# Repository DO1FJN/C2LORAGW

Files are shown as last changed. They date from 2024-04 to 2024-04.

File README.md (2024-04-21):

# Codec2 Lora Gateway

**Attention:** This project is in a very early alpha state. It lacks in some basic features and in documatation.

## Overview

This opensource project 'C2LoRaGW' connects LoRa (SemTech SX126x) based radios with internet / ham-net based repeater software.
To transport speech data using low bandwidth / bitrates C2LoRaGW uses only Codec2 within the UDP-RTP datastream.

The datastream used in the internet / ham-net derives from a 2012 project 'HAMdLNK' and uses the same format like my D-Star
proof-of-concept software from this time. A demo software 'DV-RPTR-App' was already developed and is still in use (now with
localaudio using pipewire) to test the UDP link.

On UHF side I defined 10 modes using the lower bandwidth modulations of the LoRa IC: 10,15,20 and 31kHz to transmit with 100%
duty on a frequency within 70cm ham-radio band (430-440MHz in Germany). C2LoRaGW acts as a hotspot transmitting and receiving on
the same frequency half-duplex. There is an option to add a 2nd transceiver to it and build a full duplex relay base station.

Because the fact that not ready-to-use LoRa based radios exist, this project contains also audio in- and output using cheap I2S
modules plus display an simple UI on a TFT or OLED display.

More information is in the [wiki](https://github.com/DO1FJN/C2LORAGW/wiki)

### Hardware

The project is preconfigured to run on a Heltec WiFi LoRa V3 board (433-510MHz).

A ready to use 80x50mm PCB *"C2LORAGW"* containing an E22-400M30S (or M33S) and a ESP32-S3 module is available as a KiCad
project: All spare IO's are routed to a 2.54mm pin header for adding extensions. This board can be powered by an USB 2A charger
or an LiPo / LiIon 1S battery. To simplify the design this board doesn't contain a charger or power switch jet (can be added on
a separate board). This PCB is sized to fit into an Hammond or Fisher aluminum case, but also have 4 mounting holes (M3).

More information is in the [wiki](https://github.com/DO1FJN/C2LORAGW/wiki)

### Firmware

Because the project is based around the ESP32-S3 (only this µC) the firmware needs only the EspressIf IDF developing environment.
As IDE there are some options, I used Microsoft VS Code. Setup like on EspressIf documentation described. This project uses
other opensource: Codec2 for example and the SemTech sx126x driver.

## Getting Started

First: READ all available documentation (it is not much). See "documentation" folder and use the
[wiki](https://github.com/DO1FJN/C2LORAGW/wiki).

Get some compatible hardware or build some:

Get an ESP32-S3 wroom based dev-kit or similar. Connect a SX1262 or SX1268 based Lora module (equipped for UHF!) to it. There is
almost no constrains in pinning the SPI or the additional GPIO pins needed.

### Flash Precompiled Firmware

1. Download the [ESP32 flashing utility](https://github.com/cpq/esputil).
2. Download the precompiled firmware image (ZIP file with a few binary images)
3. Flash the stuff

### Get Repository

* Install VisualStudio Code, add the EspressIf toolchain + esp-idf (or just the bare EspressIf stuff)
* Clone the repository from here (code button)
* copy one of the provided sdkconfig to "sdkconfig"
* Modify the GPIO and other settings in ./components/boards/breadboard.h or create a new board definition file for your target
* Config the project...  `idf.py menuconfig` (select the proper console for your target)
* Build + flash it... `idf.py flash`

tbd

### First Connection

Run the EspressIf monitor or something similar (Putty) to see C2LORA boot. After this, it shows a command prompt. Using typed
commands to establish a wifi connection (station mode) or change C2LORA settings, hostname, callsign and so on.

### Calibration

Because of the narrow bandwidth used a frequency calibration of crystal based LoRa modules is mandatory. The frequency needs to
be within a range of +/- 2.6kHz of the target value. TCXO radio modules are much better and a calibration is not required.

Calibration requires a frequency counter or an similar device to view a carrier in the 70cm band. Start calibration using the
command line:

`c2lora cali 1`

After this command the device transmits a continuous wave (unmodulated carrier). On the terminal the actual used offset value is
shown. Measure the difference between the carrier and the target frequency and add or subtract it from the shown offset. Type
in the new calculated offset:

`c2lora offset <new value>`

After this, the carrier moves to a new position.

**Warning:** Use an antenna or an dummy load while doing this!

A rule of thumb: Cheap crystal based modules have shown an initial offset of +17kHz below the target.

If done, turn of the transmitter with:

`c2lora cali 0`

### Save C2LORA Settings

All settings (frequency, mode, txpower and offset) are saved with the command

`c2lora save`

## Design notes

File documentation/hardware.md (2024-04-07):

# C2LoRaGW Hardware

## Prototyp 1 Board (PT01)

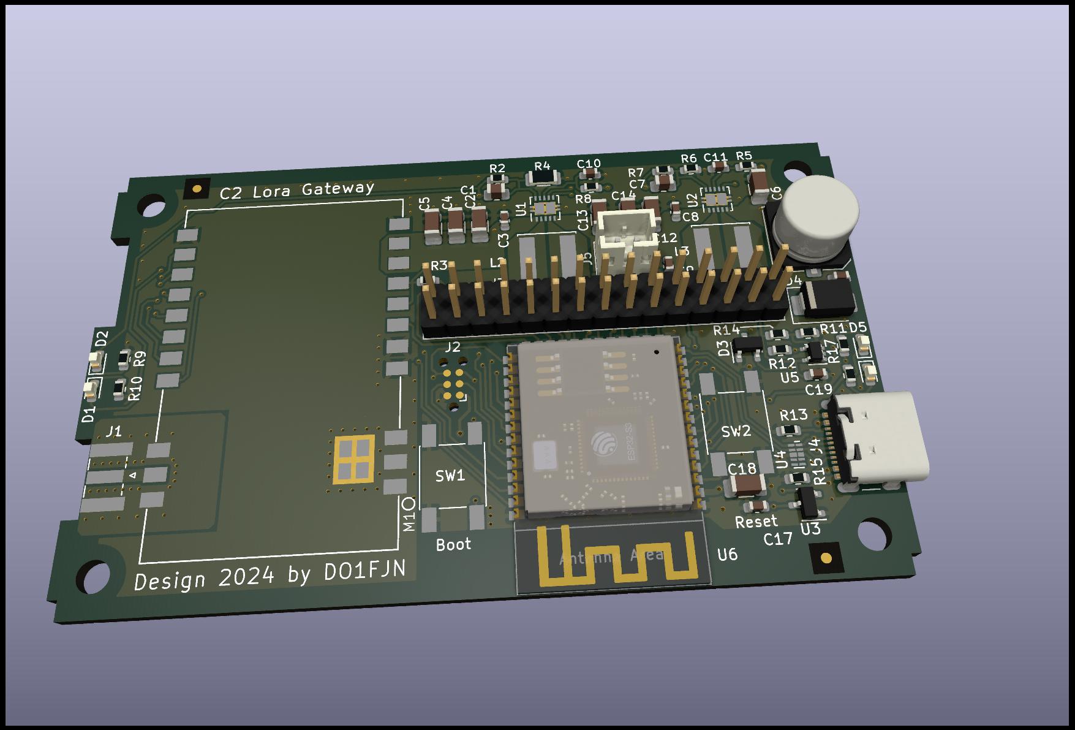
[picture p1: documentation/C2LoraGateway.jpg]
Rendering C2LORAGA Prototype 1


### Issues

ZRXE125 polarity wrong. Part needs to be "upside down" or 180° rotated. An additional capacitor is placed on R11 to
prevent fast switch on/off at the exact trigger voltage.

The 3.3VCC supply drops below APX809S31SA trigger level, if a sudden load happen on 5V rail (turning it on or transmit)
only if the input voltage is in the range between 3.8V - 3.3V (some mV above 3.3V output).

Main TPS63000 is fixed to "power save mode" - not the best decision.

### Sheet and Layout

[Sheet PDF](C2LoRaGW_sheet_PT01.pdf)

[Board Layout](C2LoRaGW_pcbtop_PT01.pdf)

## Full-Duplex Relay-Addon (FDR01)

This addon is in planning stage.

tbd

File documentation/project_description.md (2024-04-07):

# C2LoRa

## What Is C2LoRa?

C2LoRa stands for "Codec2 over LoRa". It utilizes a SemTech SX126x IC (SX1261, SX1262 or SX1268) as a transceiver for
digital speech data. This digital speech data is heavily compressed by an opensource vocoder "Codec2".

## What Is Codec2

Codec2 is a vocoder. Developed by David Rowe, Codec2 is a open source encoder and decoder specialized for human speech.
This algorithm is used to get speech data with only 3.2 down to 0.7 kbit/s (normal phone quality PCM audio: 64kbit/s).

## What Is HAMdLNK

HAMdLNK (ham radio digital voice link) is a protocol definition that adds a subframe definition to a UDP-RTP packet. It's a way
to uses UDP-RTP and pack some more information into it beside the speech data like sender, recipient and much more.

## What Is The 'Gateway'

C2 LoRa Gateway - the name of this project - describes the main function: A C2LoRa reception is forwarded to an IP address and
incoming HAMdLNK packets will be assembled and transmitted. The forwarded IP address can configured as an IPv4 broadcast or IPv6
multicast or as a URL (DNS resolvable name). IP base communication is done using the integrated

In the simplest scenario 2 devices are within the same local LAN. One uses a Gateway configuration, the other is in a 'dongle'
mode. With the 'dongle' device an operator can remotely receive and transmit away from the main station (roof antenna).

## How It Works

C2LoRa defines 10 slightly different modes. All modes in common are the use of a narrowish bandwidth (10-31kHz) and a very low
spreading factor (SF5 o SF6). For this reason the modulation isn't compatible with older SX127x IC's. In all modes speech will
be framed into 480ms long packets (6 or 12 Codec2 frames). These packets are transmitted using the mode-depended parameters. On
air such a packet is roughly as long as the voice (480ms) so that only minimal gaps exists and a transmission is near 100% duty.

The first packet of every transmission contains a tiny header so that the first transmission is between 520-580ms long.

Here is the mode overview: [C2LORA modes](C2LORA modes.md)

## Hardware Setup

This project utilizes EspressIF IDF toolchain and will compile only on a ESP32-S3 (wroom module) in the moment. This SOC is
fast enough to handle the Codec2 en- and decoding. Besides the SOC there is an module with an SX126x IC needed. In my design
it's a EByte E22-400M30S. This model is equipped with a TCXO so that the frequency is stable and even w/o calibration usable.
Module w/o a TCXO need a calibration because the frequency is very off (I measured 17kHz for my testing modules). Because of
the narrow bandwidth the modules need to be calibrated (max 2.6kHz off). Beside the power regulator(s) and a USB-C plug plus 2
buttons: That's really is it.

### Optional Hardware

There is "no limit". In the moment I added support for the common MAX98357A I2S audio amplifier and an INMP441 microphone. The
BOOT key acts as a PTT. A ST7789 TFT display can be also used. I plan to put more stuff (touchscreen support) into in so that
for example a LilyGo T-Deck can be used as a handheld radio.

### Developed Hardware

"C2LORAGW" description [here](hardware.md)

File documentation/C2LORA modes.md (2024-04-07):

# C2LORA Transmission Modes

The proper transmission mode must be known in advance. Like the frequency it is set once. There are 10 modes defined.

## Change Mode

Open a terminal / monitor to the board. Type

`c2lora mode x`

and hit enter.

(replace the 'x' with the mode number 0 to 9 or with the exact mode name (like "15kHz_1600").

## Mode Details

All modes have in common a 480ms long packet that have the same amount of Codec2 digital speech in it. There are almost no gaps
between packets. The transmitter sends out a stream of packet continuously (100% duty).

The first packet starts with a header containing some information:
* callsign (max 7 characters)
* recipient (max 7 characters, specials like "CQCQCQ" possible)
* kind of station (kos) and "was repeated" bit
* a 16bit crc for the values above
* (not in all modes) area code
* (not in all modes) locator

If configured with a frequency shift, the downstream (higher frequency, usually transmitted by a relay station / repeater) uses
inverted IQ for better separation. The upstream still uses normal IQ, same like in single frequency mode.

For all modes the SYNC WORD 1464h is used.

## Overview

| mode | name | bandwidth | SF | CR  | Codec2 | RX sensitivity | eff. bitrate |
| --- | ---- | :---: | -- | --  | -----: | ---: | ---: |
|C2M0_10LR  | 10kHz_700C | 10kHz | SF5 | 4/7 | 700C | -129.8dBm |  930bps |
|C2M1_15LR  | 15kHz_700C | 15kHz | SF6 | 4/6 | 700C | -130.6dBm |  977bps |
|C2M2_15STD | 15kHz_1300 | 15kHz | SF5 | 4/6 | 1300 | -128.1dBm | 1628bps |
|C2M3_15MQ  | 15kHz_1400 | 15kHz | SF5 | 4/6 | 1400 | -128.1dBm | 1628bps |
|C2M4_15HQ  | 15kHz_1600 | 15kHz | SF5 | 4/5 | 1600 | -128.1dBm | 1953bps |
|C2M5_20LR  | 20kHz_1300 | 20kHz | SF6 | 4/5 | 1300 | -129.3dBm | 1524bps |
|C2M6_20 | 20kHz_2400 | 20kHz | SF5 | 4/5 | 2400 | -126.8dBm | 2604bps |
|C2M7_31STD | 31kHz_1600 | 31kHz | SF6 | 4/6 | 1600 | -127.6dBm | 1953bps |
|C2M8_31LL  | 31kHz_2400 | 31kHz | SF5 | 4/7 | 2400 | -125.1dBm | 3255bps |
|C2M9_31HQ  | 31kHz_3200 | 31kHz | SF5 | 4/5 | 3200 | -125.1dBm | 3906bps |

* bandwidth (BW) refers to the double sideband (DSB)
* spreading factor (SF): only the lowest two SF are used, not compatible with SX127X devices
* FEC coding rate (CR): forward error detection + correction overhead (4/5 means 4 data bits encoded with 5 bits on air)
* effective bitrate: calculated raw bitrate over the air

## Details

### C2M0_10LR "long range"

Having only a 12.5kHz wide channel to operate, this is the only mode left. A SX126x IC can transmit even with a narrower
bandwidth of 7.8kHz, but there is no benefit to use it.

With a BW of 10.4kHz and SF5 there is room to a increased CR for better single bit error resistance . The audio quality of
Codec2 in 700C mode is acceptable.

* minimum preamble length 12 = 36.86ms
* default preamble length 15 = 46.08ms, first packet (with header) 14
* payload size = 47 bytes (1 frame start byte, 42 bytes speech data, 4 bytes for cyclic data)
* header size = 13 bytes (no area code, no locator)
* first packet onair time = 580ms

### C2M1_15LR "long range"

A 15.6kHz wide signal is used to operate in a 25kHz wide channel. Using SF6 results in longer symbol times and in a more
resilient signal at the cost of bitrate. The purpose of C2M1_15LR is to get really far out.

* default preamble length 12 = 49.15ms, first packet (with header) 14
* payload size = 48 bytes (1 frame start byte, 42 bytes speech data, 5 bytes for cyclic data)
* header size = 13 bytes (no area code, no locator)
* first packet onair time = 580ms

### C2M2_15STD "universal"

With a slightly better CR and more room for extra data this mode is versatile but still lacks in additional header information.

* minimum preamble length 12 = 24.58ms
* default preamble length 15 = 30.72ms, first packet (with header) 20
* payload size = 87 bytes (1 frame start byte, 78 bytes speech data, 8 bytes for cyclic data)
* header size = 15 bytes (with area code, no locator)
* first packet onair time = 560ms

### C2M3_15MQ "better speech"

Just like *C2M2_15STD*, but with Codec2 1400 bits per second and less additional data (slower cyclic data rate).

* minimum preamble length 12 = 24.58ms
* default preamble length 15 = 30.72ms, first packet (with header) 20
* payload size = 87 bytes (1 frame start byte, 84 bytes speech data, 2 bytes for cyclic data)
* header size = 15 bytes (with area code, no locator)
* first packet onair time = 560ms

### C2M4_15HQ "even better speech quality"

Utilizing only a CR of 4/5 gives room for more speech data in exchange for robustness.

* minimum preamble length 12 = 24.58ms
* default preamble length 14 = 28.76ms, first packet (with header) 20
* payload size = 105 bytes (1 frame start byte, 96 bytes speech data, 8 bytes for cyclic data)
* header size = 15 bytes (with area code, no locator)
* first packet onair time = 550ms

### C2M5_20LR "better quality long range"

A wider bandwidth of 20.8kHz is used in combination with SF6. So a Codec2 1300 stream will fit event with a good receiver
sensitivity. Only with the base CR of 4/5 possible.

* minimum preamble length 12 = 36.86ms (recommended by SemTech)
* default preamble length 11 = 33.79ms, first packet (with header) 13
* payload size = 81 bytes (1 frame start byte, 78 bytes speech data, 2 bytes for cyclic data)
* header size = 15 bytes (with area code, no locator)
* first packet onair time = 560ms

### C2M6_20 "speech data only"

With this mode a high quality Codec2 stream (2400) is used to get a lower latency even within a 20.8kHz wide transmission. The
latency aspect can improve repeated connection (HAMdLNK) but because of the sampling + encoding time (~32ms) there is no full
effect on a local transmission.

* minimum preamble length 12 = 18.43ms
* default preamble length 12 = 18.43ms, first packet (with header) 13
* payload size = 145 bytes (1 frame start byte, 144 bytes speech data, nothing left)
* header size = 15 bytes (with area code, no locator)
* first packet onair time = 525ms

### C2M7_31STD "widband standard"

Having room for a 31.2kHz wide transmission this mode utilizes SF6 to transport Codec2 1600.

* minimum preamble length 12 = 24.58ms
* default preamble length 16 = 32.77ms, first packet (with header) 13
* payload size = 105 bytes (1 frame start byte, 96 bytes speech data, 8 byte extra)
* header size = 21 bytes (with area code and locator)
* first packet onair time = 560ms

### C2M8_31LL "low latency"

* minimum preamble length 12 = 12.29ms
* default preamble length 12 = 12.29ms, first packet (with header) 20
* payload size = 160 bytes (1 frame start byte, 144 bytes speech data, 15 byte extra)
* header size = 15 bytes (with area code, no locator)
* first packet onair time = 530ms

### C2M9_31HQ "high quality"

At the cost of bandwidth, FEC and RX sensitivity this it the mode to transport Codec2 at the highest quality possible.

* minimum preamble length 12 = 12.29ms
* default preamble length 13 = 13.31ms, first packet (with header) 14
* payload size = 222 bytes (1 frame start byte, 192 bytes speech data, 29 byte extra)
* header size = 20 bytes (with area code and locator)
* first packet onair time = 520ms

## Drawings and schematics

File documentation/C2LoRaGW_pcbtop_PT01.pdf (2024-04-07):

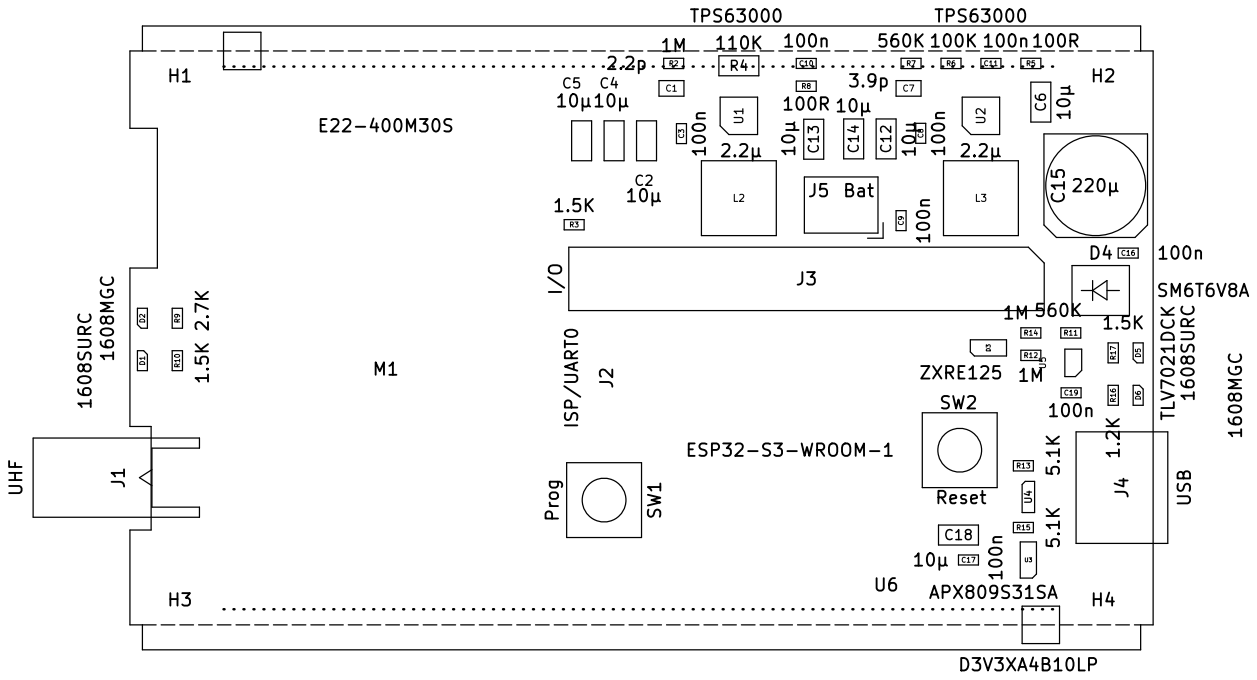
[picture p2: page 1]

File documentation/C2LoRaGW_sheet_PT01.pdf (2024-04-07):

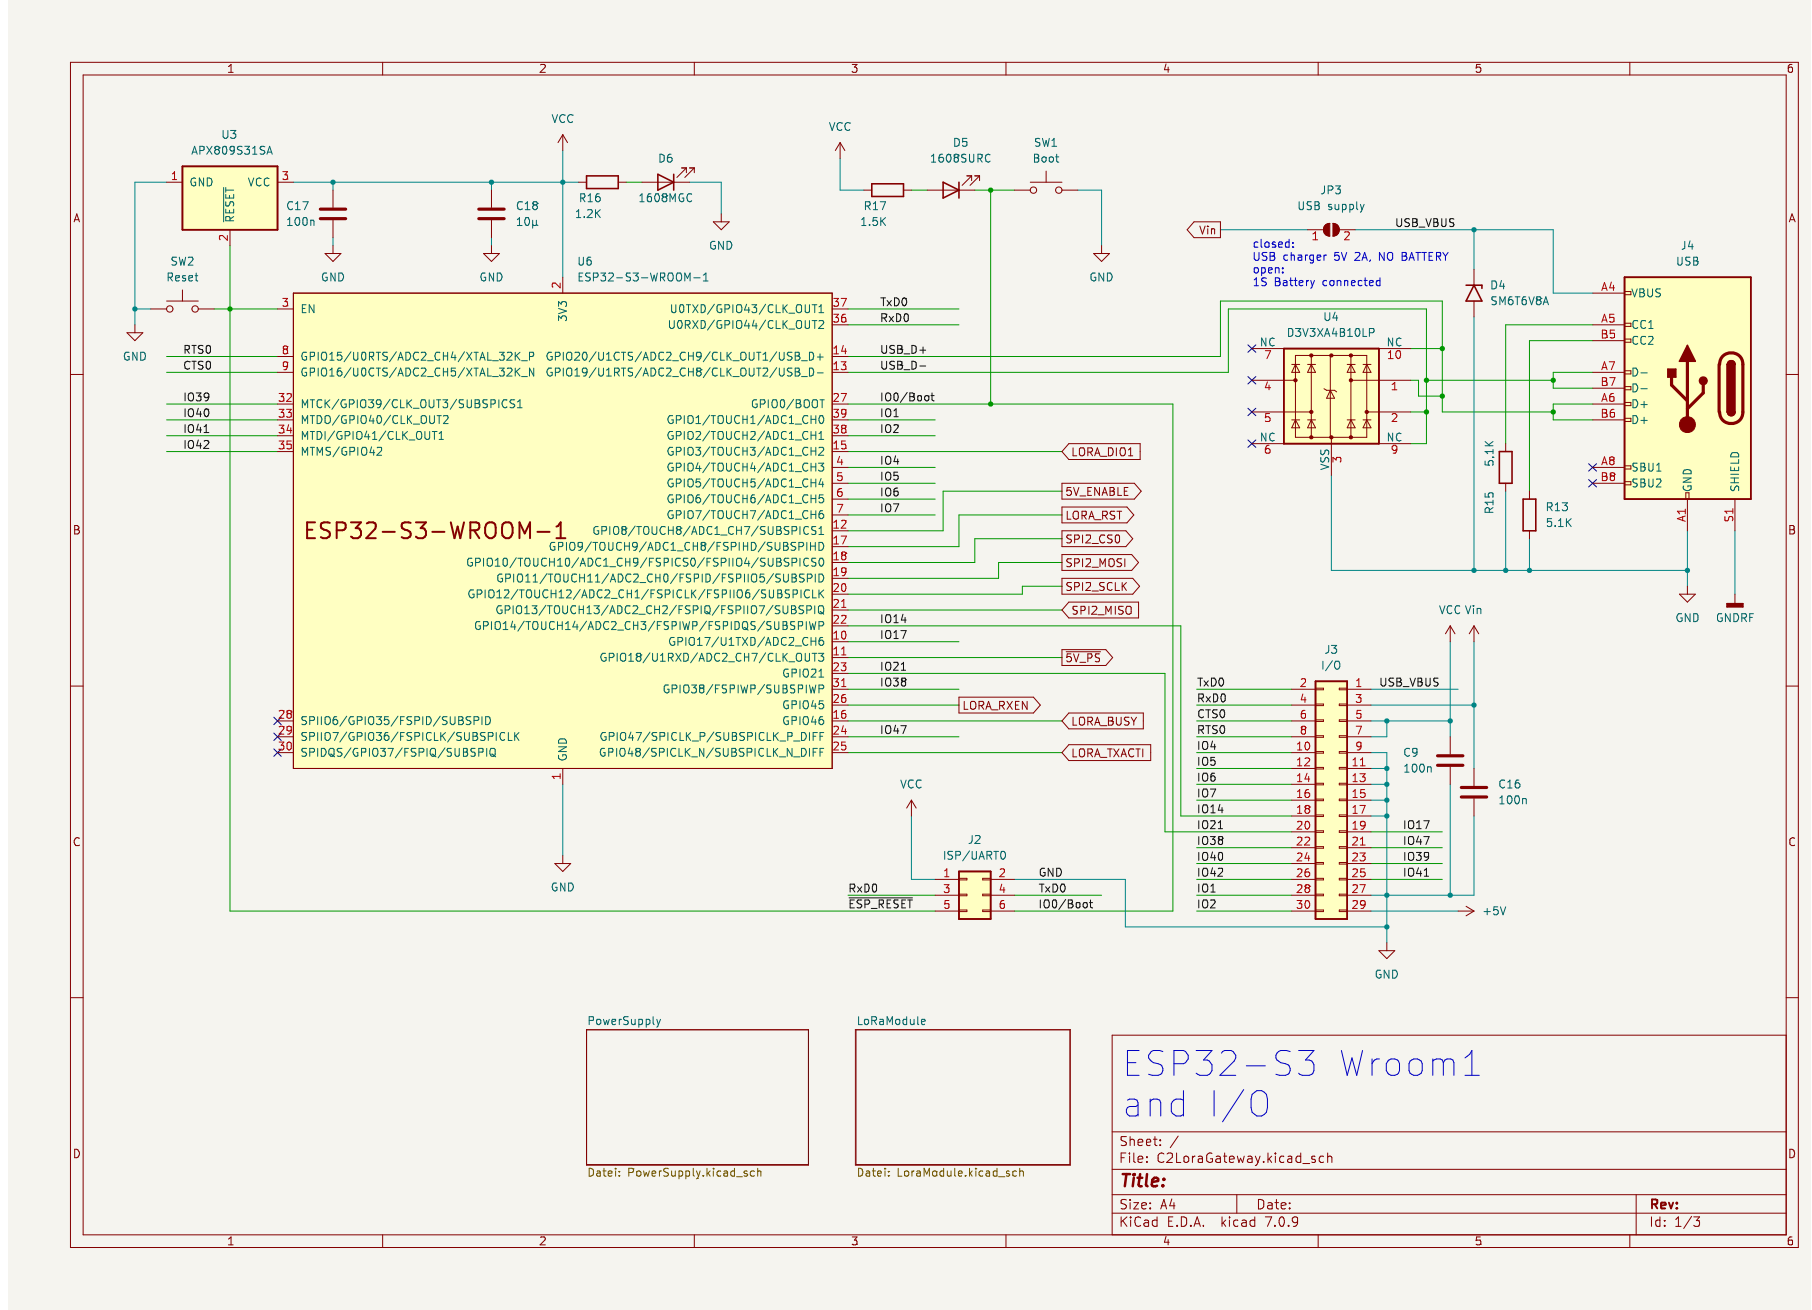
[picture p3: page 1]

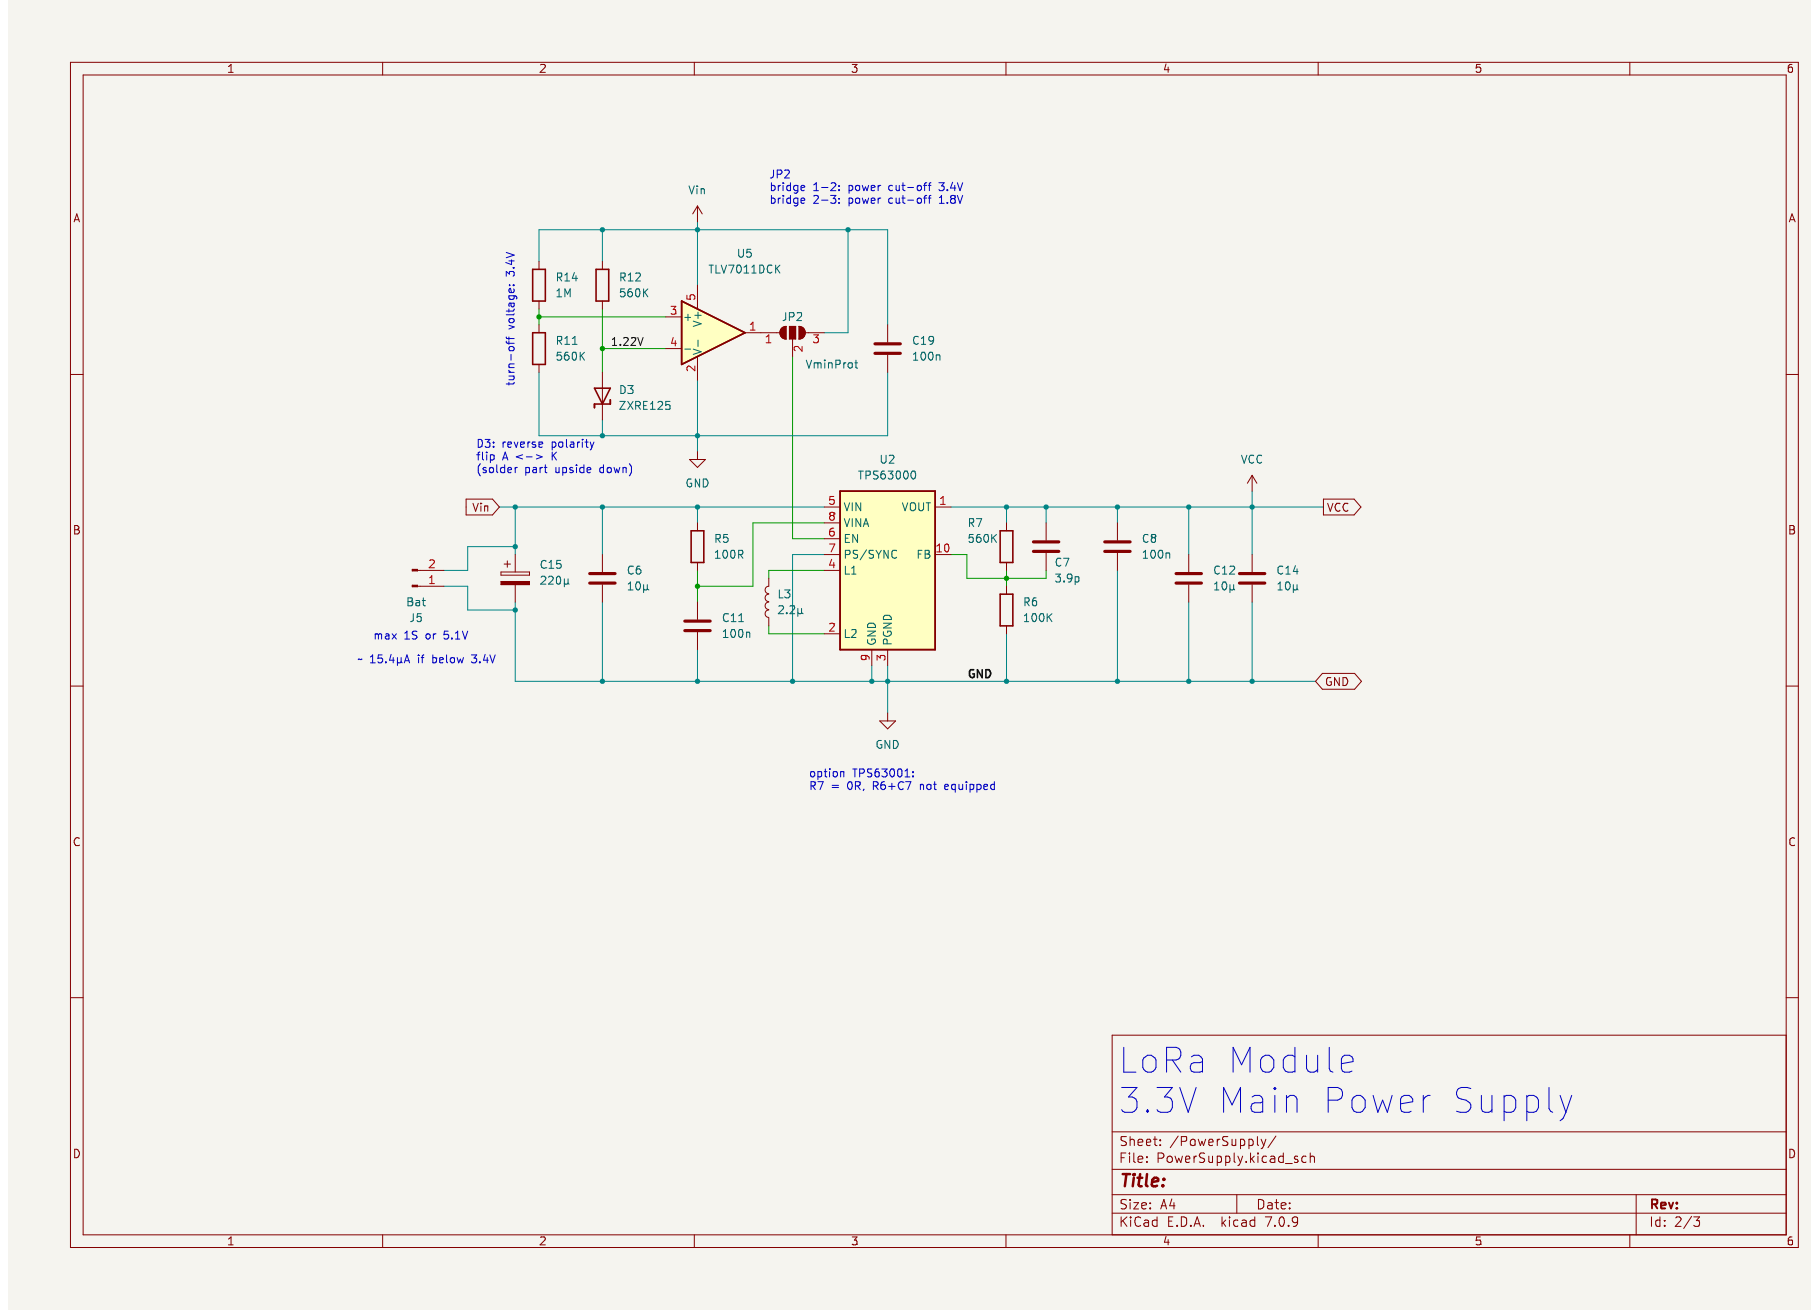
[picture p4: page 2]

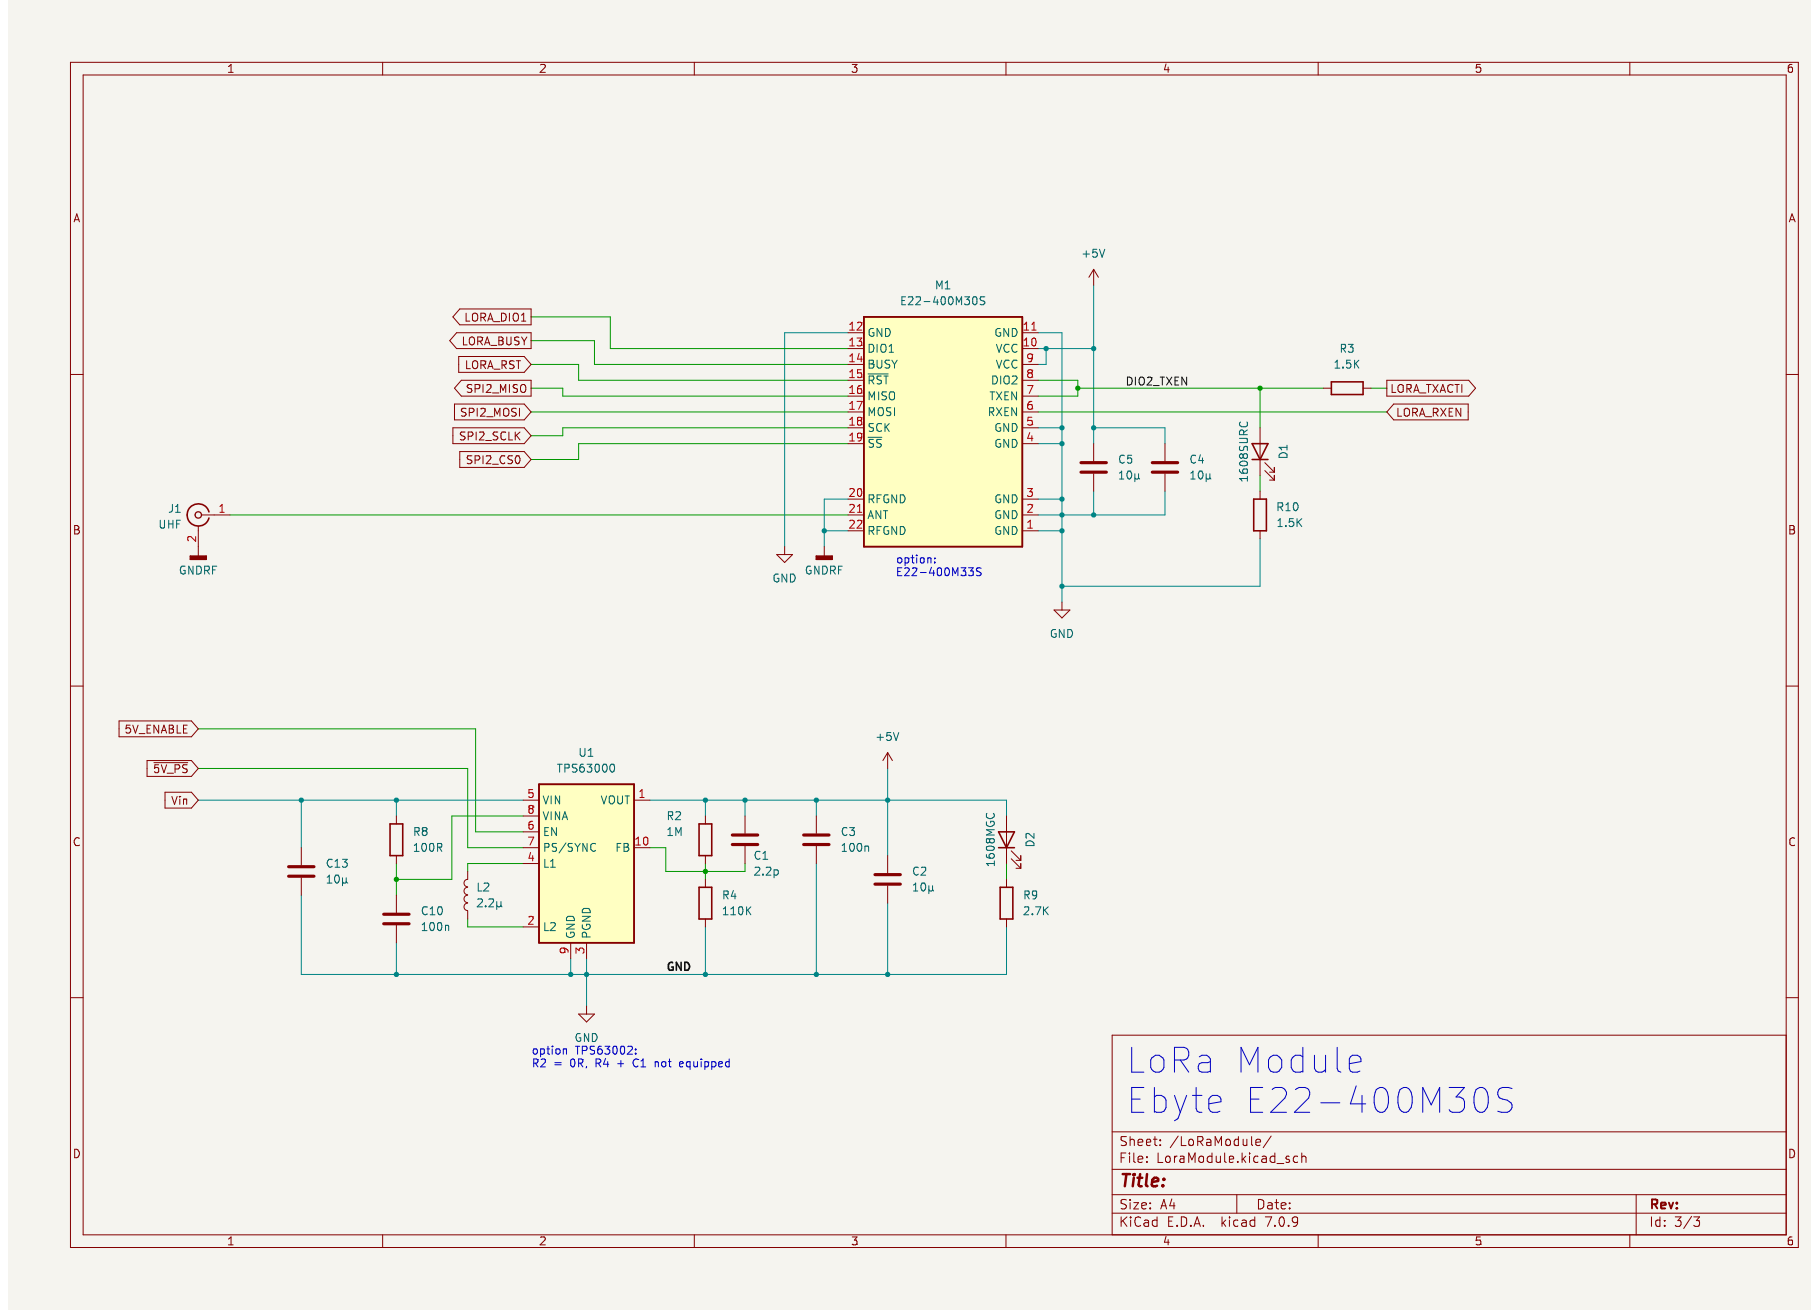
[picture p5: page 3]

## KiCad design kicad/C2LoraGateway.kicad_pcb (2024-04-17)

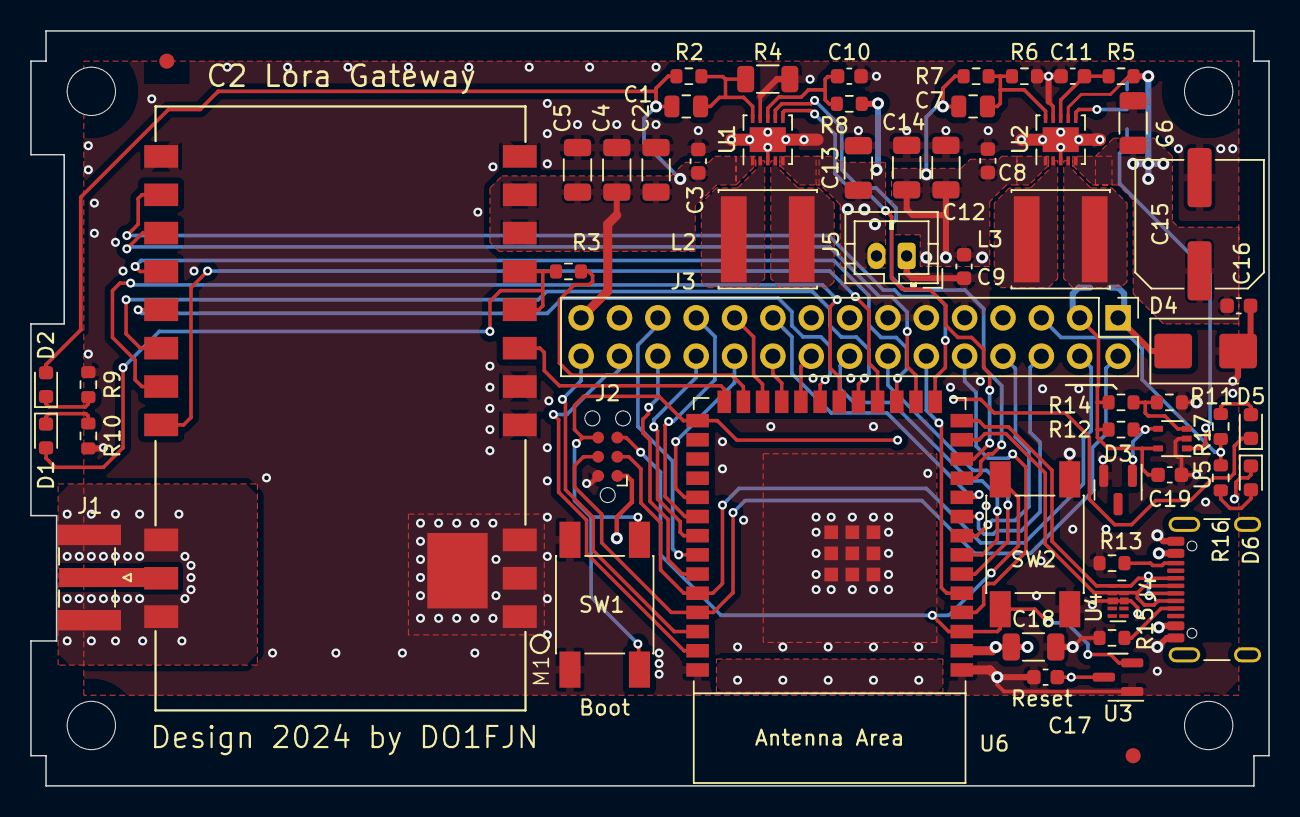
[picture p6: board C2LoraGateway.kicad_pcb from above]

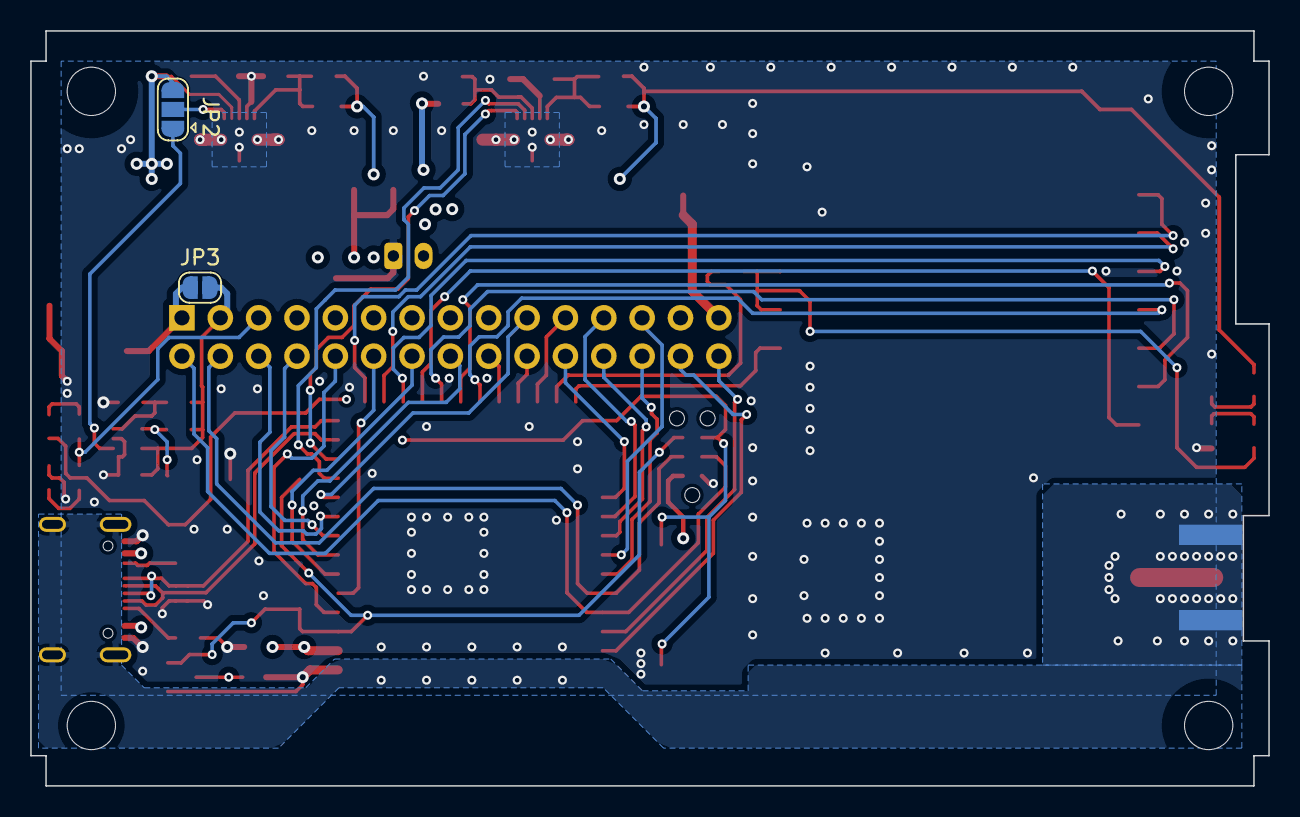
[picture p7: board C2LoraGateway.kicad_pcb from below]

Board: 4 copper layers, 82.0 x 50.0 mm, 65 parts (2 on the bottom side), 60 nets.

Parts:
C1: 2.2p; C_0805_2012Metric
C2, C4, C5, C6, C12, C13, C14, C18: 10µ; C_1206_3216Metric
C3, C8, C9, C10, C11, C16, C17, C19: 100n; C_0603_1608Metric
C7: 3.9p; C_0805_2012Metric
C15: 220µ; C_Elec_8x6.2
D1, D5: 1608SURC; LED_0603_1608Metric
D2, D6: 1608MGC; LED_0603_1608Metric
D3: ZXRE125; SOT-23
D4: SM6T6V8A; D_SMB
FID1, FID2: Fiducial_1mm_Sqare; Fiducial_1mm_Square
H1, H2, H3, H4: MountingHole_3.2mm_M3
J1: UHF; SMA_Samtec_SMA-J-P-X-ST-EM1_EdgeMount
J2: ISP/UART0; Tag-Connect_TC2030-IDC-NL_2x03_P1.27mm_Vertical
J3: I/O; PinHeader_2x15_P2.54mm_Vertical
J4: USB; USB_C_Receptacle_GCT_USB4105-xx-A_16P_TopMnt_Horizontal
J5: Bat; JST_PH_B2B-PH-K_1x02_P2.00mm_Vertical
JP2: VminProt; SolderJumper-3_P1.3mm_Open_RoundedPad1.0x1.5mm
JP3: USB supply; SolderJumper-2_P1.3mm_Open_RoundedPad1.0x1.5mm
L2, L3: 2.2µ; L_Changjiang_FNR6045S
M1: E22-400M30S
R2, R14: 1M; R_0603_1608Metric
R3, R10, R17: 1.5K; R_0603_1608Metric
R4: 110K; R_1206_3216Metric
R5, R8: 100R; R_0603_1608Metric
R6: 100K; R_0603_1608Metric
R7, R11, R12: 560K; R_0603_1608Metric
R9: 2.7K; R_0603_1608Metric
R13, R15: 5.1K; R_0603_1608Metric
R16: 1.2K; R_0603_1608Metric
SW1: Boot; SW_Push_Switronic_IT1102WB8
SW2: Reset; SW_Push_Switronic_IT1102WB8
U1, U2: TPS63000; Texas_DRC0010J
U3: APX809S31SA; SOT-23
U4: D3V3XA4B10LP; Diodes_UDFN-10_1.0x2.5mm_P0.5mm
U5: TLV7011DCK; SOT-353_SC-70-5
U6: ESP32-S3-WROOM-1

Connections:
5V_ENABLE: U1.6 (EN), U6.12 (GPIO8/TOUCH8/ADC1_CH7/SUBSPICS1)
+5V: C1.1, C2.1, C3.1, C4.1, C5.1, D2.2 (A), J3.29, M1.9 (VCC), M1.10 (VCC), R2.2, U1.1 (VOUT)
/CTS0: J3.6, U6.9 (GPIO16/U0CTS/ADC2_CH5/XTAL_32K_N)
/IO0/Boot: D5.1 (K), J2.6, SW1.1, U6.27 (GPIO0/BOOT)
/IO1: J3.28, U6.39 (GPIO1/TOUCH1/ADC1_CH0)
/IO2: J3.30, U6.38 (GPIO2/TOUCH2/ADC1_CH1)
/IO4: J3.10, U6.4 (GPIO4/TOUCH4/ADC1_CH3)
/IO5: J3.12, U6.5 (GPIO5/TOUCH5/ADC1_CH4)
/IO6: J3.14, U6.6 (GPIO6/TOUCH6/ADC1_CH5)
/IO7: J3.16, U6.7 (GPIO7/TOUCH7/ADC1_CH6)
/IO14: J3.18, U6.22 (GPIO14/TOUCH14/ADC2_CH3/FSPIWP/FSPIDQS/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)
/IO17: J3.19, U6.10 (GPIO17/U1TXD/ADC2_CH6)
/IO21: J3.20, U6.23 (GPIO21)
/IO38: J3.22, U6.31 (GPIO38/FSPIWP/SUBSPIWP)
/IO39: J3.23, U6.32 (MTCK/GPIO39/CLK_OUT3/SUBSPICS1)
/IO40: J3.24, U6.33 (MTDO/GPIO40/CLK_OUT2)
/IO41: J3.25, U6.34 (MTDI/GPIO41/CLK_OUT1)
/IO42: J3.26, U6.35 (MTMS/GPIO42)
/IO47: J3.21, U6.24 (GPIO47/SPICLK_P/SUBSPICLK_P_DIFF)
/LoRaModule/DIO2_TXEN: D1.2 (A), M1.7 (TXEN), M1.8 (DIO2), R3.1
/PowerSupply/1.22V: D3.1 (K), R12.1, U5.4 (-)
/RTS0: J3.8, U6.8 (GPIO15/U0RTS/ADC2_CH4/XTAL_32K_P)
/RxD0: J2.3, J3.4, U6.36 (U0RXD/GPIO44/CLK_OUT2)
/TxD0: J2.4, J3.2, U6.37 (U0TXD/GPIO43/CLK_OUT1)
/USB_D+: J4.A6 (D+), J4.B6 (D+), U4.1, U4.10 (NC), U6.14 (GPIO20/U1CTS/ADC2_CH9/CLK_OUT1/USB_D+)
/USB_D-: J4.A7 (D-), J4.B7 (D-), U4.2, U4.9 (NC), U6.13 (GPIO19/U1RTS/ADC2_CH8/CLK_OUT2/USB_D-)
/USB_VBUS: D4.1 (A1), J3.1, J4.A4 (VBUS), J4.A9 (VBUS), J4.B4 (VBUS), J4.B9 (VBUS), JP3.2 (B)
/~ESP_RESET: J2.5, SW2.2, U3.2 (~RESET), U6.3 (EN)
GND: C2.2, C3.2, C4.2, C5.2, C6.2, C8.2, C9.2, C10.2, C11.2, C12.2, C13.2, C14.2, C15.2, C16.2, C17.2, C18.2, C19.2, D3.2 (A), D4.2 (A2), D6.1 (K), J2.2, J3.9, J3.11, J3.13, J3.15, J3.17, J3.27, J4.A1 (GND), J4.A12 (GND), J4.B1 (GND), J4.B12 (GND), J5.1, M1.1 (GND), M1.2 (GND), M1.3 (GND), M1.4 (GND), M1.5 (GND), M1.11 (GND), M1.12 (GND), R4.1, R6.1, R9.1, R10.1, R11.1, R13.2, R15.2, SW1.2, SW2.1, U1.3 (PGND), U1.9 (GND), U1.11 (PGND), U2.3 (PGND), U2.9 (GND), U2.11 (PGND), U3.1 (GND), U4.3 (VSS), U4.8 (VSS), U5.2 (V-), U6.1 (GND), U6.40 (GND), U6.41 (GND)
GNDRF: J1.2 (Ext), J4.S1 (SHIELD), M1.20 (RFGND), M1.22 (RFGND)
LORA_BUSY: M1.14 (BUSY), U6.16 (GPIO46)
LORA_DIO1: M1.13 (DIO1), U6.15 (GPIO3/TOUCH3/ADC1_CH2)
LORA_RST: M1.15 (~RST), U6.17 (GPIO9/TOUCH9/ADC1_CH8/FSPIHD/SUBSPIHD)
LORA_RXEN: M1.6 (RXEN), U6.26 (GPIO45)
LORA_TXACTI: R3.2, U6.25 (GPIO48/SPICLK_N/SUBSPICLK_N_DIFF)
unnamed: D1.1 (K), R10.2
unnamed: D2.1 (K), R9.2
unnamed: D5.2 (A), R17.2
unnamed: D6.2 (A), R16.2
unnamed: J1.1 (In), M1.21 (ANT)
unnamed: J4.A5 (CC1), R15.1
unnamed: J4.B5 (CC2), R13.1
unnamed: JP2.1 (A), U5.1
unnamed: JP2.2 (C), U2.6 (EN)
unnamed: C1.2, R2.1, R4.2, U1.10 (FB)
unnamed: L2.2, U1.4 (L1)
unnamed: L2.1, U1.2 (L2)
unnamed: C10.1, R8.1, U1.8 (VINA)
unnamed: C7.2, R6.2, R7.1, U2.10 (FB)
unnamed: L3.2, U2.4 (L1)
unnamed: L3.1, U2.2 (L2)
unnamed: C11.1, R5.1, U2.8 (VINA)
unnamed: R11.2, R14.1, U5.3 (+)
SPI2_CS0: M1.19 (~SS), U6.18 (GPIO10/TOUCH10/ADC1_CH9/FSPICS0/FSPIIO4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)
SPI2_MISO: M1.16 (MISO), U6.21 (GPIO13/TOUCH13/ADC2_CH2/FSPIQ/FSPIIO7/S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)
SPI2_MOSI: M1.17 (MOSI), U6.19 (GPIO11/TOUCH11/ADC2_CH0/FSPID/FSPIIO5/S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)
SPI2_SCLK: M1.18 (SCK), U6.20 (GPIO12/TOUCH12/ADC2_CH1/FSPICLK/FSPIIO6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)
VCC: C7.1, C8.1, C9.1, C12.1, C14.1, C17.1, C18.1, J2.1, J3.5, J3.7, R7.2, R16.1, R17.1, U2.1 (VOUT), U3.3 (VCC), U6.2 (3V3)
Vin: C6.1, C13.1, C15.1, C16.1, C19.1, J3.3, J5.2, JP2.3 (B), JP3.1 (A), R5.2, R8.2, R12.2, R14.2, U1.5 (VIN), U2.5 (VIN), U2.7 (PS/SYNC), U5.5 (V+)
~5V_PS: U1.7 (PS/SYNC), U6.11 (GPIO18/U1RXD/ADC2_CH7/CLK_OUT3)

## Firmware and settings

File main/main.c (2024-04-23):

/*

C2 LoRa Gateway

This file is the main source file of project 'C2LoRaGW'.
(c) 2024, DO1FJN (Jan Alte)

Unless required by applicable law or agreed to in writing, this
software is distributed on an "AS IS" BASIS, WITHOUT WARRANTIES OR
CONDITIONS OF ANY KIND, either express or implied.

*/

#include "sdkconfig.h"

#include "hardware.h"

#include "ui.h"

#include "MasterIni.h"
#include "utilities.h"

#include "C2LORA.h"
#include "C2LORA_modes.h"
#include "C2LORA_header.h"
#include "c2lora_uhf.h"
#include "C2LORA_hamdlnk.h"

#include "LAN.h"
#include "HAMdLNK.h"
#include "hamdlnk2audio.h"
#include "localaudio.h"

#include "driver/gpio.h"

#include "esp_log.h"
#include "esp_check.h"

#include "esp_chip_info.h"
#include "esp_flash.h"
#include "esp_system.h"
#include "esp_spiffs.h"
#include "nvs.h"
#include "nvs_flash.h"
#include "esp_event.h"
#include "esp_console.h"
#include "argtable3/argtable3.h"

#include "freertos/FreeRTOS.h"
#include "freertos/task.h"
#include <string.h>
#include <stdio.h>
#include <fcntl.h>


#ifdef TFT_HOST
#include "TFT.h"
#endif

#ifdef OLED_IF_TYPE
#include "OLED.h" // for tests only
#endif


typedef enum {
  SM_OFFLINE, SM_DONGLE, SM_STANDBY, SM_ONAIR, SM_NOWIFI
} tStartupMode;


/*
 * We warn if a secondary serial console is enabled. A secondary serial console is always output-only and
 * hence not very useful for interactive console applications. If you encounter this warning, consider disabling
 * the secondary serial console in menuconfig unless you know what you are doing.
 */
#if SOC_USB_SERIAL_JTAG_SUPPORTED
#if !CONFIG_ESP_CONSOLE_SECONDARY_NONE
#warning "A secondary serial console is not useful when using the console component. Please disable it in menuconfig."
#endif
#endif

#define PROMPT_STR    CONFIG_DEVICE_NAME

#define NTP_DEFAULT_URL		"pool.ntp.org"


static const char *TAG = "LoRaGW";

#define ASCIIartlines 6
static const char *ASCIIartTitle[ASCIIartlines] = {
" _____  _____  _          ______      _____ _    _ ",
"/  __ \\/ __  \\| |         | ___ \\    |  __ \\ |  | |",
"| /  \\/`' / /'| |     ___ | |_/ /__ _| |  \\/ |  | |",
"| |      / /  | |    / _ \\|    // _` | | __| |/\\| |",
"| \\__/\\./ /___| |___| (_) | |\\ \\ (_| | |_\\ \\  /\\  /",
" \\____/\\_____/\\_____/\\___/\\_| \\_\\__,_|\\____/\\/  \\/ "
};



static const char *APP_namespace    = "C2LORAGW";

static const char *APP_startupmode  = "start_opmode";
static const char *APP_sendto_host  = "sendto_host";
static const char *APP_sendto_host2 = "sendto_host2";

static const char *APP_callsign     = "callsign";
static const char *APP_recipient    = "destination";
static const char *APP_kindofsender = "k_o_s";
static const char *APP_areacode     = "areacode";
static const char *APP_locator      = "locator";

static const char *APP_volume       = "volume";
static const char *APP_micgain      = "micgain";


static const tHAMdLNK_network_config ham2lnk_default_config = {
  .sendto_hostname_uhf = "broadcast",
  .sendto_port_uhf    = CONFIG_HAMDLNK_PORT_MAIN,  // received C2LORA frames are forwarded to this port
  .listen_port_uhf    = CONFIG_HAMDLNK_PORT_MAIN,
  .sendto_hostname_dongle = "broadcast",
  .sendto_port_dongle = CONFIG_HAMDLNK_PORT_2ND,  // local audio from microphoe are send to this port (can be the same as UHF)
  .listen_port_dongle = CONFIG_HAMDLNK_PORT_2ND
};


static char cmd_prompt[24];


static void app_set_default_debuglevel(void) {
#if CONFIG_LOG_DEFAULT_LEVEL > 1
  esp_log_level_set("*", ESP_LOG_INFO);    
  esp_log_level_set("wifi", ESP_LOG_WARN);
  esp_log_level_set("wifi-init", ESP_LOG_WARN);
  //esp_log_level_set("wpa", ESP_LOG_VERBOSE);
  //esp_log_level_set("WiFiSTA", ESP_LOG_VERBOSE);

  esp_log_level_set("LoRaGW", ESP_LOG_VERBOSE);
  esp_log_level_set("UI", ESP_LOG_VERBOSE);
  //esp_log_level_set("LAN", ESP_LOG_VERBOSE);
  //esp_log_level_set("UDPan", ESP_LOG_VERBOSE);
  //esp_log_level_set("NTPclient", ESP_LOG_VERBOSE);

  //esp_log_level_set("OLED", ESP_LOG_VERBOSE);
  //esp_log_level_set("SSD1306", ESP_LOG_VERBOSE);
  //esp_log_level_set("TFT", ESP_LOG_VERBOSE);
  //esp_log_level_set("ST7789", ESP_LOG_VERBOSE);

  esp_log_level_set("C2LORA", ESP_LOG_VERBOSE);
  //esp_log_level_set("C2LORAcore", ESP_LOG_VERBOSE);
  //esp_log_level_set("C2LRA_HDR", ESP_LOG_VERBOSE);
  //esp_log_level_set("C2LORA-UDP", ESP_LOG_VERBOSE);
  //esp_log_level_set("HdL2AUDIO", ESP_LOG_DEBUG);
  //esp_log_level_set("LocalAudio", ESP_LOG_VERBOSE);

  
  //esp_log_level_set("S_SPI", ESP_LOG_VERBOSE);  
  //esp_log_level_set("i2s_loop", ESP_LOG_VERBOSE);
  //esp_log_level_set("gdma", ESP_LOG_VERBOSE);
#endif
}


static esp_err_t fs_open(void) {
  static const esp_vfs_spiffs_conf_t fsconf = {
    .base_path = "/ifs",
    .partition_label = NULL,
    .max_files = 5,
    .format_if_mount_failed = false
  };
  ESP_LOGD(TAG, "Initializing SPIFFS");

  esp_err_t ret = esp_vfs_spiffs_register(&fsconf);
  if (ret != ESP_OK) {
    if (ret == ESP_FAIL) {
      ESP_LOGE(TAG, "Failed to mount filesystem");
    } else if (ret == ESP_ERR_NOT_FOUND) {
      ESP_LOGE(TAG, "Failed to find SPIFFS partition");
    } else {
      ESP_LOGE(TAG, "Failed to initialize SPIFFS (%s)", esp_err_to_name(ret));
    }
    return ret;
  }
#if CONFIG_LOG_DEFAULT_LEVEL > 2
  size_t total = 0, used = 0;
  ret = esp_spiffs_info(NULL, &total, &used);
  if (ret != ESP_OK) {
    ESP_LOGE(TAG, "Failed to get SPIFFS partition information (%s)", esp_err_to_name(ret));
  } else {
    ESP_LOGI(TAG, "Partition size: total: %d, used: %d", total, used);
  }
#endif
  return ret;
}

static void fs_close(void) {
  esp_vfs_spiffs_unregister(NULL);
}


#define BLINK_PATTERN_NOSPI     0x0
#define BLINK_PATTERN_NOI2C     0x0
#define BLINK_PATTERN_NOWIFI    0x0
#define BLINK_PATTERN_NOHAMDLNK 0x0
#define BLINK_PATTERN_NOAUDIO   0x0
#define BLINK_PATTERN_NOC2LORA  0x0


static void stop_boot_with_fail(uint32_t blink_pattern) {
  ESP_LOGE(TAG, "stopped with fail blink pattern %08lxh", blink_pattern);
#if CONFIG_BOOT_FAIL_LED != GPIO_NUM_NC
  uint32_t shift_pattern;
  gpio_set_level(CONFIG_BOOT_FAIL_LED, 1);
  gpio_set_direction(CONFIG_BOOT_FAIL_LED, GPIO_MODE_OUTPUT_OD);
  while(1) {
    shift_pattern = blink_pattern;
    for (int i=32; i>0; i--, shift_pattern <<= 1) {
      gpio_set_level(CONFIG_BOOT_FAIL_LED, shift_pattern & 0x80000000L? 0: 1);
      vTaskDelay(pdMS_TO_TICKS(250));
    }    
    vTaskDelay(pdMS_TO_TICKS(2000));
  } // ehliw
#else
  while(1) {
    vTaskDelay(10);
  } // ehliw
#endif
}


/*
  fwversion = OTG_GetVersionAsUInt();
  sprintf(UDP_BC_answer, UDP_BC_fmtstr, Param->myname,
    fwversion>>12, (fwversion>>4)&0xFF, (fwversion&0x0F)? ('a'+(fwversion&0x0F)-1): ' ',
    Param->tcp_port, Param->backlog, Param->ssl_port);
*/


static int app_print_chipinfo(int argc, char **argv) {
  // Print chip information
  const char *model;
  esp_chip_info_t chip_info;
  uint32_t flash_size;
  esp_chip_info(&chip_info);
  switch (chip_info.model) {
  case CHIP_ESP32:
    model = "ESP32";
    break;
  case CHIP_ESP32S2:
    model = "ESP32-S2";
    break;
  case CHIP_ESP32S3:
    model = "ESP32-S3";
    break;
  case CHIP_ESP32C3:
    model = "ESP32-C3";
    break;
  case CHIP_ESP32H2:
    model = "ESP32-H2";
    break;
  case CHIP_ESP32C2:
    model = "ESP32-C2";
    break;
  default:
    model = "Unknown " CONFIG_IDF_TARGET;
    break;
  } // hctiws
  printf("\nThis is %s chip with %d CPU core(s), %s%s%s%s, ", model, chip_info.cores,
         (chip_info.features & CHIP_FEATURE_WIFI_BGN) ? "WiFi/" : "",
         (chip_info.features & CHIP_FEATURE_BT) ? "BT" : "",
         (chip_info.features & CHIP_FEATURE_BLE) ? "BLE" : "",
         (chip_info.features & CHIP_FEATURE_IEEE802154)? ", 802.15.4 (Zigbee/Thread)": "");

  unsigned major_rev = chip_info.revision / 100;
  unsigned minor_rev = chip_info.revision % 100;
  printf("silicon revision v%d.%d, ", major_rev, minor_rev);
  if (esp_flash_get_size(NULL, &flash_size) != ESP_OK) {
    printf("Get flash size failed");
    return 1;
  }
  printf("%" PRIu32 "MB %s flash\n", flash_size / (uint32_t)(1024 * 1024), (chip_info.features & CHIP_FEATURE_EMB_FLASH) ? "embedded" : "external");
  printf("IDF Version: %s\r\n", esp_get_idf_version());
  printf("Internal free heap size: %" PRIu32 " bytes\n\n", esp_get_free_internal_heap_size());
  return 0;
}


static int app_print_memory_usage(int argc, char **argv) {
  printf("int free heap size: %" PRIu32 " bytes\n", esp_get_free_internal_heap_size());
  printf("min free heap size: %" PRIu32 " bytes\n", esp_get_minimum_free_heap_size());
  printf("    free heap size: %" PRIu32 " bytes\n", esp_get_free_heap_size());  

  printf("MALLOC_CAP_EXEC     %d bytes\n", heap_caps_get_free_size( MALLOC_CAP_EXEC ));
  printf("MALLOC_CAP_INTERNAL %d bytes\n", heap_caps_get_free_size( MALLOC_CAP_INTERNAL ));
  printf("MALLOC_CAP_32BIT    %d bytes\n", heap_caps_get_free_size( MALLOC_CAP_32BIT ));
  printf("MALLOC_CAP_DEFAULT  %d bytes\n", heap_caps_get_free_size( MALLOC_CAP_DEFAULT ));
  return 0;
}


static int restart(int argc, char **argv) {
  ESP_LOGI(TAG, "Restarting...");
  esp_restart();
//  return 0; meckern????
}


static void register_chipinfo(void) {
  const esp_console_cmd_t cmd = {
    .command = "chipinfo",
    .help = "Get model/revision and features of this SOC and IDF version",
    .hint = NULL,
    .func = &app_print_chipinfo,
  };
  ESP_ERROR_CHECK(esp_console_cmd_register(&cmd));
}

static void register_free(void) {
  const esp_console_cmd_t cmd = {
    .command = "free",
    .help = "Get the current size of free heap memory",
    .hint = NULL,
    .func = &app_print_memory_usage,
  };
  ESP_ERROR_CHECK(esp_console_cmd_register(&cmd));
}

static void register_restart(void) {
  const esp_console_cmd_t cmd = {
    .command = "restart",
    .help = "Software reset of the SOC",
    .hint = NULL,
    .func = &restart,
  };
  ESP_ERROR_CHECK(esp_console_cmd_register(&cmd));
}



// log_level command changes log level via esp_log_level_set

static struct {
    struct arg_str *tag;
    struct arg_str *level;
    struct arg_end *end;
} log_level_args;

static const char *s_log_level_names[] = {
    "none", "error", "warn", "info", "debug", "verbose"
};


static int log_level(int argc, char **argv) {
  int nerrors = arg_parse(argc, argv, (void **)&log_level_args);
  if (nerrors != 0) {
    arg_print_errors(stderr, log_level_args.end, argv[0]);
    return 1;
  }
  assert(log_level_args.tag->count == 1);
  assert(log_level_args.level->count == 1);
  const char *tag = log_level_args.tag->sval[0];
  const char *level_str = log_level_args.level->sval[0];
  esp_log_level_t level;
  size_t level_len = strlen(level_str);
  for (level = ESP_LOG_NONE; level <= ESP_LOG_VERBOSE; level++) {
    if (memcmp(level_str, s_log_level_names[level], level_len) == 0) {
      break;
    }
  } //rof
  if (level > ESP_LOG_VERBOSE) {
    printf("Invalid log level '%s', choose from none|error|warn|info|debug|verbose\n", level_str);
    return 1;
  }
  if (level > CONFIG_LOG_MAXIMUM_LEVEL) {
    printf("Can't set log level to %s, max level limited in menuconfig to %s. "
      "Please increase CONFIG_LOG_MAXIMUM_LEVEL in menuconfig.\n",
      s_log_level_names[level], s_log_level_names[CONFIG_LOG_MAXIMUM_LEVEL]);
    return 1;
  }
  esp_log_level_set(tag, level);
  return 0;
}

static void register_log_level(void) {
  log_level_args.tag   = arg_str1(NULL, NULL, "<tag|*>", "Log tag to set the level for, or * to set for all tags");
  log_level_args.level = arg_str1(NULL, NULL, "<none|error|warn|info|debug|verbose>", "Log level to set. Abbreviated words are accepted.");
  log_level_args.end   = arg_end(2);

  const esp_console_cmd_t cmd = {
    .command = "log_level",
    .help = "Set log level for all tags or a specific tag.",
    .hint = NULL,
    .func = &log_level,
    .argtable = &log_level_args};
  ESP_ERROR_CHECK(esp_console_cmd_register(&cmd));
}


void register_main_console_cmd(void) {
  register_free();
  register_chipinfo();
  register_restart();
  register_log_level();
}



void ntp_time_notifier(int now) {
  printf("time has changed to %d\n", now);
}




#include "C2LORA_modes.h"

static void print_mode_delay_table(void) {
  for (tC2LORA_mode m = C2M_MIN; m <= C2M_MAX; m++) {
     // hint: all byte lengths are 1 byte short, because we need the time before buffer on length-pos is read by SX126x
     const tC2LORAdef *def = C2LORA_get_parameter4mode(m);     
     uint32_t symbol_time  = c2lora_calc_symboltime(def);
     uint32_t frame_bytes  = (sf_get_subframe_bits(def->codec_type) * def->dv_frames_per_packet + 7) >> 3; // bytes till all DV is xmited
     uint32_t header_time  = c2lora_calc_firstprefetch(def, symbol_time, def->bytes_per_header, true);
     uint32_t frame_time   = c2lora_calc_firstprefetch(def, symbol_time, frame_bytes, false);
     uint32_t hframe_time  = c2lora_calc_firstprefetch(def, symbol_time, def->bytes_per_header + frame_bytes, true);
     uint32_t fframe_time  = c2lora_calc_firstprefetch(def, symbol_time, def->bytes_per_packet, false);
     printf("C2M%d %s:\n", m, C2LORA_get_mode_name(m));
     printf("symbol time: %luµs\t\ttransmission time: %luµs (%d bytes)\n", symbol_time, fframe_time, def->bytes_per_packet);
     printf("time to first DV is needed: %luµs (header pkt)\n", header_time);
     printf("time to last DV is needed : %luµs (header pkt)\t %ldµs to start\n", hframe_time, (int32_t)480000 - (int32_t)hframe_time);
     printf("time to last DV is needed : %luµs (frame pkt with %lu speech bytes)\n", frame_time, frame_bytes);
     // caluclate:
     uint32_t max_time_last = frame_time - symbol_time - (symbol_time >> 1); // minus 1.5x symbol time so that is a safty margin fort correction next frame
     uint32_t min_time_last = max_time_last - ( 4 * symbol_time);
     printf("calc sfe parameter: %lums..%lums\n", (min_time_last) / 1000,  (max_time_last) / 1000);
     printf("mode parameter set: %dms..%dms\n\n", 480-def->min_finish_ms + (def->dv_frames_per_packet==24? 20:40), 480-def->max_finish_ms + (def->dv_frames_per_packet==24? 20:40));
     // caculate time needed in the first fram
  } // rof all.
}


static void print_c2lora_info(bool with_table) {
  int freq_hz  = C2LORA_get_frequency();
  int freq_sft = C2LORA_get_freqshift();
  tC2LORA_mode mode = C2LORA_get_mode();
  double freqf = (double)freq_hz / 1000000;
  double fshftf = (double)freq_sft / 1000000;
  C2LORA_print_status();
  printf("tuned to %8.4fMHz (%+6.4f TX), mode: C2M%d %s\n\n", freqf, fshftf, mode, C2LORA_get_mode_name(mode));
  if (with_table) {
     print_mode_delay_table();
  }
}


static int32_t parse_frequency_mhz(const char *freq_str) {
  int32_t freq_hz = 0;
  char *fraction_str;
  long freq_mhz = strtol(freq_str, &fraction_str, 10);
  if ((fraction_str != freq_str) && (fraction_str[0] != 0)) {
    if (fraction_str[0] != '.') {
      printf("invalid frequency format (xxx.y{z} MHz)\n");
      return 0x80000000;
    }
    fraction_str++;    
    for (int p=0; p < 6; p++) {
      freq_hz *= 10;
      if ((fraction_str[0] >= '0') && (fraction_str[0] <= '9')) {
        freq_hz += fraction_str[0] - '0';
        fraction_str++;
      } // fi
    }
  } // fi 
  if ((freq_mhz >= 0) & (freq_str[0] != '-')) {
    freq_hz += freq_mhz * 1000000L;
  } else {
    freq_hz = (freq_mhz * 1000000L) - freq_hz;
  }
  return freq_hz;
}


static void set_c2lora_frequency(int argc, const char **argv) {
  int32_t freq_hz = parse_frequency_mhz(argv[0]);
  int32_t freq_sft = 0;
  if (freq_hz == 0x80000000) {
    printf("invalid frequency format (xxx.y{z} MHz)\n");
    return;
  }
  if (argc > 1) {
    freq_sft = parse_frequency_mhz(argv[1]);
    if (freq_sft == 0x80000000) {
      printf("invalid frequency shift format (-/+x.y{z} MHz)\n");
      return;
    }
  }
  if (((freq_hz + freq_sft) >= C2LORA_MIN_FREQ_HZ) && ((freq_hz + freq_sft) <= C2LORA_MAX_FREQ_HZ)) {
    printf("set frequency to %luHz %+ldHz\n\n", freq_hz, freq_sft);
    C2LORA_set_frequency(freq_hz, freq_sft);
  } else { // fi
    printf("frequency out of bounds.\n");
  }
}
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
void app_main(void) {
  esp_err_t ret;
  tStartupMode startup_mode = SM_STANDBY;

  tHAMdLNK_network_config ham2lnk_config = ham2lnk_default_config;

  esp_console_repl_t *      repl        = NULL;
  esp_console_repl_config_t repl_config = ESP_CONSOLE_REPL_CONFIG_DEFAULT();
  strncpy(cmd_prompt, PROMPT_STR ">", sizeof(cmd_prompt));    // Prompt to be printed before each line.
  repl_config.prompt = cmd_prompt;
  repl_config.max_cmdline_length = 128;

  app_set_default_debuglevel();

  ret = nvs_flash_init();
  if (ret == ESP_ERR_NVS_NO_FREE_PAGES) {
    ESP_ERROR_CHECK(nvs_flash_erase());
    ret = nvs_flash_init();
  }
  ESP_ERROR_CHECK(ret);

  ESP_ERROR_CHECK(esp_event_loop_create_default());	// create default system event loop

  fs_open();

  board_gpio_init();   // initialize important GPIO together at start.

#if (defined I2C_SDA_Pin) && (I2C_SDA_Pin != GPIO_NUM_NC)
  ret = board_i2c_init();
  if (ret != ESP_OK) {
    ESP_LOGE(TAG, "*** I2C init fail ***");
    stop_boot_with_fail(BLINK_PATTERN_NOI2C);
  }
#endif

// Todo load all in om funcion
  startup_mode = get_app_config_from_nvs(&ham2lnk_config);

  if (startup_mode <= SM_NOWIFI) {
    printf("startup mode: %s\n", startup_modes[startup_mode]);
  }

#if (defined BOARD_POWER_ON_Pin) && (BOARD_POWER_ON_Pin != GPIO_NUM_NC)
  vTaskDelay(pdMS_TO_TICKS(150));  // wait powering up 5V...
#endif
  // *** Enable S_SPI Module ***
  if (C2LORA_init_spi() != ESP_OK) {
    ESP_LOGE(TAG, "SPI 4 SX126x init fails");
    stop_boot_with_fail(BLINK_PATTERN_NOSPI);
  }

#if CONFIG_LOCALAUDIO_ENABLED
  if (localaudio_start() != ESP_OK) {
    ESP_LOGE(TAG, "*** no audio - no task! ***");
    stop_boot_with_fail(BLINK_PATTERN_NOAUDIO);
  }
#endif

  // *** Enable WiFi Module ***
  if ((startup_mode < SM_NOWIFI) && (startup_mode > SM_OFFLINE)) {
    if (LAN_init() != ESP_OK) {
      ESP_LOGE(TAG, "WiFi init fails");
      stop_boot_with_fail(BLINK_PATTERN_NOWIFI);
    }
    // update command prompt with hostname:
    snprintf(cmd_prompt, sizeof(cmd_prompt), "%s>", LAN_get_hostname());
    ESP_LOGD(TAG, "new promt: '%s'", cmd_prompt);
  } // fi wifi


#if defined(CONFIG_ESP_CONSOLE_UART_DEFAULT) || defined(CONFIG_ESP_CONSOLE_UART_CUSTOM)
  esp_console_dev_uart_config_t hw_config = ESP_CONSOLE_DEV_UART_CONFIG_DEFAULT();
  ESP_ERROR_CHECK(esp_console_new_repl_uart(&hw_config, &repl_config, &repl));

#elif defined(CONFIG_ESP_CONSOLE_USB_CDC)
  esp_console_dev_usb_cdc_config_t hw_config = ESP_CONSOLE_DEV_CDC_CONFIG_DEFAULT();
  ESP_ERROR_CHECK(esp_console_new_repl_usb_cdc(&hw_config, &repl_config, &repl));

#elif defined(CONFIG_ESP_CONSOLE_USB_SERIAL_JTAG)
  esp_console_dev_usb_serial_jtag_config_t hw_config = ESP_CONSOLE_DEV_USB_SERIAL_JTAG_CONFIG_DEFAULT();
  ESP_ERROR_CHECK(esp_console_new_repl_usb_serial_jtag(&hw_config, &repl_config, &repl));

#else
#error Unsupported console type
#endif

  // Register commands
  esp_console_register_help_command();
  register_main_console_cmd();

  register_localsetfunct();

  if (startup_mode > SM_DONGLE) {
    ret = C2LORA_init_tranceiver(SX126X_DEVICE_NUM, CONFIG_DEFAULT_FREQUENCY_HZ, CONFIG_DEFAULT_C2LORA_MODE, SX126X_FREQUENCY_OFFSET);
    if (ret == ESP_OK) {
      register_c2lora();   
#ifdef SX126X_2_DEVICE_NUM      
      C2LORA_init_tranceiver_2(SX126X_2_DEVICE_NUM, SX126X_2_FREQUENCY_OFFSET);
#endif
      if (startup_mode >= SM_ONAIR) {
        C2LORA_start_continuous_rx(true);
      }
    } else {
      ESP_LOGE(TAG, "*** no UHF link! ***");
      stop_boot_with_fail(BLINK_PATTERN_NOC2LORA);
    }
  } else { // fi not DONGLE
    C2LORA_init_donglemode(CONFIG_DEFAULT_C2LORA_MODE);
  }

  set_c2lora_header();

  // *** Start WiFi Station Mode OR Ethernet ***
  if ((startup_mode < SM_NOWIFI) && (startup_mode > SM_OFFLINE)) {
    ret = LAN_start();
    if (ret == ESP_OK) {
      ntp_startclienttask(INI_get_NTPurl(NTP_DEFAULT_URL), ntp_time_notifier);

      if (C2LORA_start_udp_task(&ham2lnk_config) != ESP_OK) {
        ESP_LOGE(TAG, "*** can't listen to UDP-RTP HAMdLNK - no task. ***");
        stop_boot_with_fail(BLINK_PATTERN_NOHAMDLNK);
      }

    } else {    
      ESP_ERROR_CHECK(ret);
    }    
  }

  ret = ui_Init();
  if (ret != ESP_OK) {
    ESP_LOGW(TAG, "NO UI! Init of user interface (UI) failed.");
  }

  vTaskDelay(2); // wait for ESP_LOG messages (trom running tasks)
  for (int l=0; l < ASCIIartlines; l++) {
    printf("%s\n", ASCIIartTitle[l]);
  } // rof

  ESP_ERROR_CHECK(esp_console_start_repl(repl));

  if (ret == ESP_OK) { // last result from ui_Init()
    ret = ui_Start();
    if (ret != ESP_OK) {
      ESP_LOGW(TAG, "Start of user interface (UI) failed.");
    }
  } // fi ok

  while (startup_mode == SM_DONGLE) {
    if (ptt_button_state(true)) {
      ESP_LOGI(TAG, "*** start streaming ***");
      ret = ham2lnk_broadcast_audio(C2LORA_get_codec_type(), 240, true, "");
      if (ret != ESP_OK) {
        ESP_LOGE(TAG, "*** error streaming *** (%s)", esp_err_to_name(ret));
        break;    
      }
      do {
        vTaskDelay(pdMS_TO_TICKS(60));
      } while (ptt_button_state(false));
      ESP_LOGI(TAG, "*** end streaming ***");
      ham2lnk_broadcast_stop();
    } // fi tx HAMdLNK
    vTaskDelay(10);
  } // ehliw dongle operation

#if CONFIG_LOCAL_PTT_ENABLED
  while (1) {
    if (ptt_button_state(true)) {
      ESP_LOGI(TAG, "*** start transmitting ***");
      ret = C2LORA_start_tx_microphone();
      if (ret != ESP_OK) {  
        ESP_LOGE(TAG, "*** error transmitting *** (%s)", esp_err_to_name(ret));
        break;    
      }
//      ESP_LOGI(TAG, "high stack water mark is %u\n", uxTaskGetStackHighWaterMark(NULL));
      do {
        vTaskDelay(pdMS_TO_TICKS(120));
      } while (ptt_button_state(false));

      ESP_LOGI(TAG, "*** end transmitting ***");
      C2LORA_end_tx_microphone();
    } // fi tx local
    vTaskDelay(10);
  } // ehliw foirever
#endif
  
  fs_close(); 

} // END main

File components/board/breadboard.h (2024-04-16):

/*
This header file contain to project 'C2LoRaGW'.
(c) 2024, DO1FJN (Jan Alte)

hardware GPIO defines for a ESP32-S3 Noname HMI Board with TFT Display mounted ta a bread board
*/

#pragma once

#define PROG_BUTTON_Pin         0       // IO0

//#define I2C_SDA_Pin             45
//#define I2C_SCL_Pin             4


#define TFT_BACKLIGHT_PIN       14

#define TFT_HOST                SPI2_NUM
#define TFT_DEVICE_NUM          0
#define TFT_SPISPEED_MHZ        26

#define TFT_SCK_Pin		12
#define TFT_MOSI_Pin		13
#define TFT_MISO_Pin            GPIO_NUM_NC
#define TFT_DC_Pin	        11
#define TFT_CS_Pin	        10
#define TFT_RST_Pin	        1

#define	TFT_X_SIZE		320
#define TFT_Y_SIZE		170
#define TFT_BYTE_PER_COLOR	2
#define TFT_CTRL_POSITION       RIGHT
#define TFT_Y_OFFSET            35


//#define OLED_IF_TYPE            0       // (0) I2C, (1) SPI
//#define	OLED_X_SIZE		128
//#define OLED_Y_SIZE		64
//#define OLED_CTRL_POSITION      BOTTOM
//#define OLED_Y_OFFSET           0


#define AUDIO_I2S_WS_Pin        5
#define AUDIO_I2S_DOUT_Pin      6
#define AUDIO_I2S_BCLK_Pin      7

#define CODEC_I2S_DIN_Pin       48
#define CODEC_I2S_BCLK_Pin      47
#define CODEC_I2S_WS_Pin        21


#define AUDIO_I2S_ENABLE        17


#define SX126X_RX_BOOST_GAIN    0       // no boost

#define SX126X_HOST             SPI3_NUM
#define SX126X_SPISPEED_MHZ     10

#define SX126X_SCK_Pin		38
#define SX126X_MOSI_Pin		39
#define SX126X_MISO_Pin         40
#define SX126X_RST_Pin	        2

#define SX126X_DEVICE_NUM       0
#define SX126X_FREQUENCY_OFFSET   17450
#define SX126X_NSS_Pin	        41
#define SX126X_BUSY_Pin	        42
#define SX126X_DIO1_Pin         15
//#define SX126X_DIO3_Pin       16

#define SX126X_2_DEVICE_NUM     1
#define SX126X_2_FREQUENCY_OFFSET   18300
#define SX126X_2_NSS_Pin	    20
#define SX126X_2_BUSY_Pin           18
#define SX126X_2_DIO1_Pin           19
//#define SX126X_DIO3_Pin 

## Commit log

2024-04-08 c2lora_uhf.c: Fix re-enable receive mode after transmit fails
    [c2lora_uhf.c]
2024-04-08 Update C2LORA_core.c and c2lora_uhf.c: update free space calulation, added some few ticks to the first timeout => fixes mode 9
    [C2LORA_core.c, c2lora_uhf.c]
2024-04-10 Added support for Heltec WiFi LoRa 32 V3 boards
    [PartTable08MiB.csv]
2024-04-11 Update heltec_wifi_lora_v3.h - some comments + port-power pin
2024-04-16 in the moment there is a shortage of peripheral interrupts: I²C on breadboard is disabled (needed 4 touch) + no TFT AND OLED together (not designed for this)
    [breadboard.h]
2024-04-16 TFT select (SPI device) and Wait4Completion added
2024-04-17 Update board layout (same schematic, only bugfixes + layout imporvements)
    [C2LoraGateway.kicad_pcb, PowerSupply.kicad_sch]
2024-04-17 Added OLED reset GPIO pin setup for Heltec LoRa 32 display
2024-04-22 Update board definition Heltec WiFi LoRa V3 (free LED IO)
2024-04-22 Adding LED_Pin init
2024-04-22 A lot of rework, adding an ECHO function (a reception with recipient "ECHO" will be transmitted back)
    [C2LORA.h, c2lora_uhf.c]
2024-04-23 set and get txpower bugfix
    [C2LORA_core.c, c2lora_uhf.c, main.c]
2024-04-23 Update T-Deck target, still not functional (missing SPI management for UI)
    [heltec_wifi_lora_v3.h, lilygo_tdeck.h]
